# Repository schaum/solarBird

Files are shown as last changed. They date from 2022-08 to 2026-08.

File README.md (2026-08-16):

# Twittering E-Solar-Bird with ATtiny13-Chip

Do you want to improve the world with electronics? Then this solar-powered E-Bird is for you. This bird alternative operates completely autonomously and is friendly in any climate. The bird starts chirping on its own as soon as there's a bit of light.

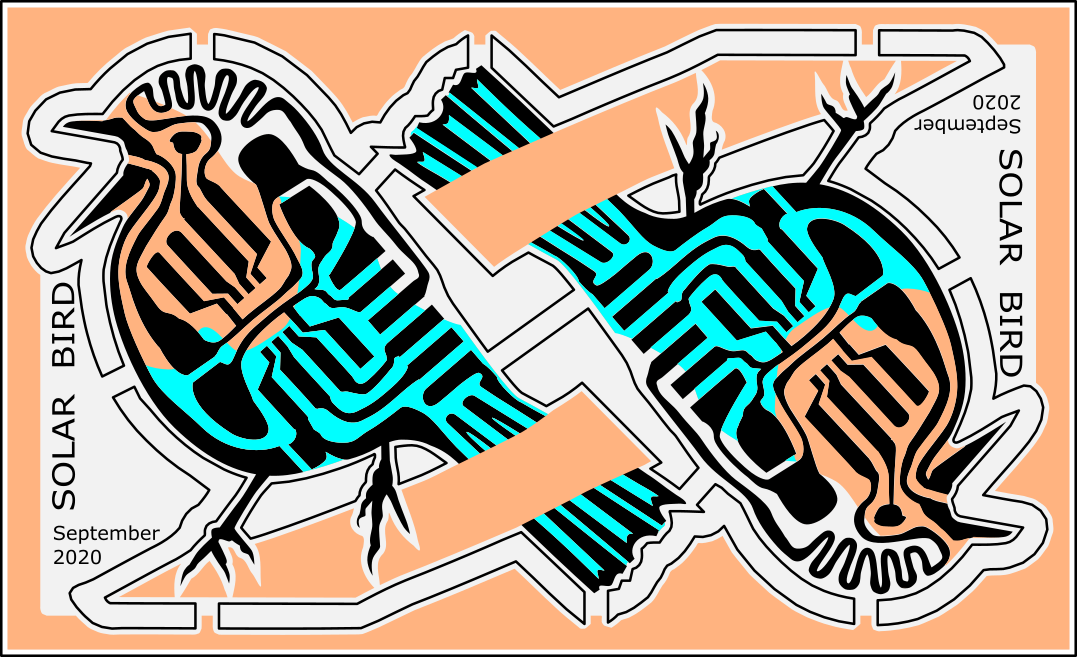
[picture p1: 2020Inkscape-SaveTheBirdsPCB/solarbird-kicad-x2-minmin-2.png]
SolraBird-PCB
This is how the circuit board design looks like. 

Freshly programmed, the bird also twitters. It adjusts its enthusiasm according to light conditions. The program is easily adjustable, which is why we've used this circuit for workshops, for example in schools.

In this project you find my chirping program and circuit board.

Some details for the old, still analog version of the solar bird you can find on [this page](http://mechatronicart.ch/diymakeaway/solarbird).

Protect the species!

This project has grown [within the community](https://mechatronicart.ch/). The basis comes from Christoph Haberer. Sounddesign and circuit board by [taube.xyz](/pick/kontakt), Spring 2011 and September 2020.

For some more pictures, visit [this homepage](https://taube.xyz/pick/solarbird).

## Some hints and advices building

- The twittering program works best on ATtiny13 or ATtiny13V chips. **Avoid the newer ATtiny13A chips.** The reason is, that these newer chips interrupt the programm, when the voltge drops a certain level. This is normally a good thing. But the behavior of the chips without the "A" is more interesting for the solar bird: the internal clock gets slower, and so the chirping gets slower and deeper in sound as well. This is perfect for manipulation of the twittering by making shadows on the solar cell. Also, you can program very fast twitterings and make them hearable when you put the bird into the shadow.
- The circuit board is designed so that you can use SMD-Chips, but as well the DIL-chips with the long legs. Simply bend the legs 90 degrees and solder them onto the surface. No need to drill holes.
- For programming the chip, there are 6 pins in a row on the backbones of the bird, from head to tail: GND, 5V, RESET, SCK, MISO, MOSI. It's easy there to solder a single row of pin-headers.
- If you want to program the chip without disconnecting the piezo speaker, you can add a resistor in between the speaker and the chip. There is a gap on the track in the lower part of the circuit board between pin 5 of the chip and the beak of the bird. Bridge it with a resistor of maybe 1K max.
- If you want to add sensors to the ADC of the chip, beware that the ADC doesn't work securely when the voltage drops very low. The working of the chip with very low voltages is a main feature of this solar bird. Test it well, if it works the way you like!

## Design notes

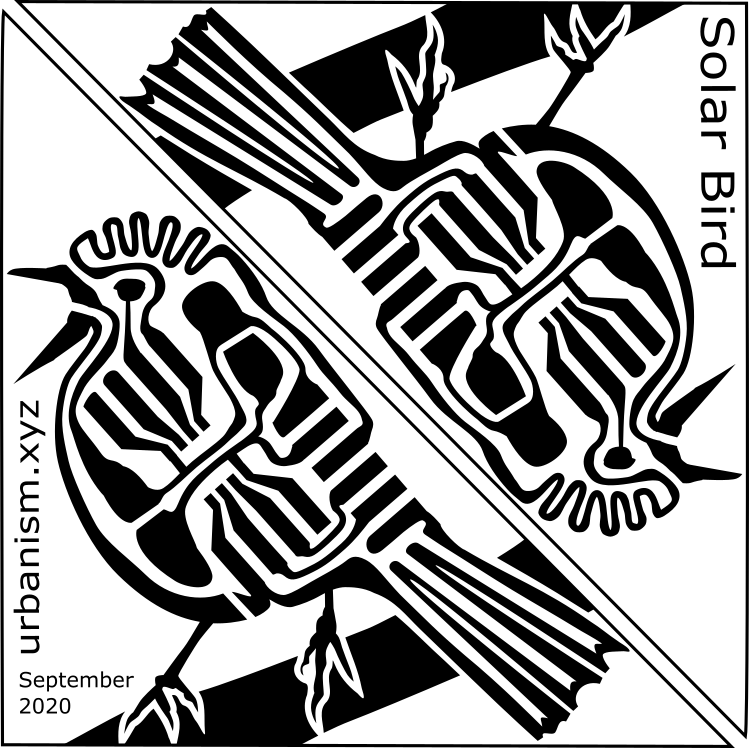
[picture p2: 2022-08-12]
2020Inkscape-SaveTheBirdsPCB/solarbirdx2.png

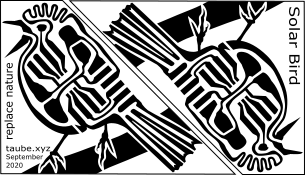
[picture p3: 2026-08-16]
2020Inkscape-SaveTheBirdsPCB/solarbirdx2v2.png

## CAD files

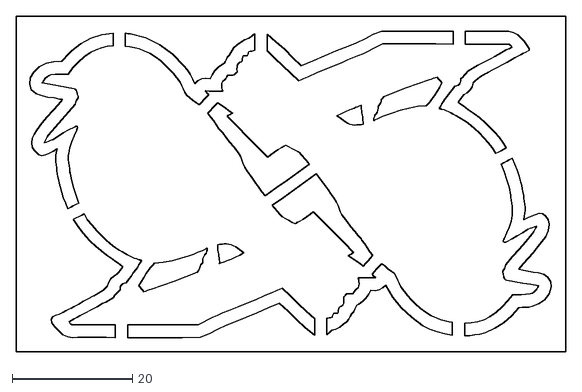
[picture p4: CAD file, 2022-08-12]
2020Inkscape-SaveTheBirdsPCB/solarbird-kicad-x2-minmin-cut.dxf
91.3 x 55.6

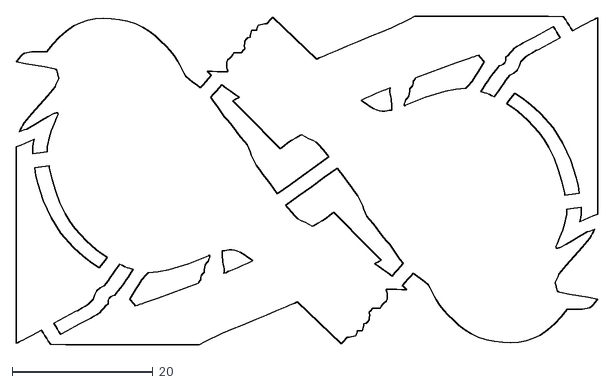
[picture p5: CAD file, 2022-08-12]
2020Inkscape-SaveTheBirdsPCB/solarbird-kicad-x2-cut.dxf
82.6 x 46.7

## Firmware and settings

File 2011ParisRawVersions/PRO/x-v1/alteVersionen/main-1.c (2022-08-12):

 /*************************************************************************

   solar frog

   attiny 13 slow clock low power experiments

   28.9.08 christoph(at)roboterclub-freiburg.de
   15.9.10 urbanbieri(at)gmx.ch

*************************************************************************/
/*************************************************************************

   Hardware
   
   prozessor:   ATtin13
   clock:      128Khz internal oscillator

   PIN1   RESET         
   PIN2   PORTB3/ADC3    ADC- light sensitive sensor  
   PIN3   PORTB4/ADC2      
   PIN4   GND

   PIN5   PORTB0/OC10    piezo controll speaker
   PIN6   PORTB1         record button
   PIN7   PORTB2/ADC1      
   PIN8   VCC

*************************************************************************/
#include <avr/io.h>
#include <avr/eeprom.h>


#define PIEZOSPEAKER 	(1<<PINB0)
#define SENSOR 			(1<<PINB3)
#define BUTTON 			(1<<PINB1)

#define LOADSECONDS 60

#define HZ_1706 2
#define HZ_853 4
#define HZ_586 6
#define HZ_426 8

//GLOBAL VARIABLES
	uint16_t tone_d = 100;
	uint16_t pause_d = 500;
	int8_t pitchstep = 1;

void init_sensor(void){
	
	DDRB &= ~(SENSOR); //set SENSOR pin as input
	// Enable ADC: ADEN to 1.
	// Prescaler 128: ADPS2-0: set to 1
	// enable the Conversion Complete Interrupt: ADIE to 1
	ADCSRA = (1 << ADEN) | (1 << ADPS2) | (1 << ADPS1) | (1 << ADPS0);
}

// sets LED-PWM value from LSR value (light sensitive resistor)
uint8_t start_conversion(void){
// for 8-bit precision I select left Adjustet representation (ADLAR) so that I only have
// to read the ADCH byte. REFS0=0: reference voltage VCC
	ADMUX = (1 << ADLAR) | (0 << REFS0) | 0x11; // 0x01 is PB2, 0x10 is PB4, 0x11 is PB3.
	ADCSRA |= (1 << ADSC);			// Start conversion
	while (!(ADCSRA & (1 << ADIF)));	// wait for conversion complete	
	ADCSRA |= (1 << ADIF);			// clear ADCIF
	return(ADCH);
}

//EEPROM examples from the Attiny13 manual, page 13.
void EEPROM_write(uint8_t ucAddress, uint8_t ucData) { 
	/* Wait for completion of previous write */ 
	while(EECR & (1<<EEPE)); 
	/* Set Programming mode */ 
	EECR = (0<<EEPM1)|(0>>EEPM0);
	/* Set up address and data registers */ 
	EEARL = ucAddress; 
	EEDR = ucData; 
	/* Write logical one to EEMPE */ 
	EECR |= (1<<EEMPE); 
	/* Start eeprom write by setting EEPE */ 
	EECR |= (1<<EEPE); 
}
uint8_t EEPROM_read(uint8_t ucAddress) { 
	/* Wait for completion of previous write */ 
	while(EECR & (1<<EEPE)); 
	/* Set up address register */ 
	EEARL = ucAddress; 
	/* Start eeprom read by writing EERE */ 
	EECR |= (1<<EERE); 
	/* Return data from data register */ 
	return EEDR; 
}

void init_button(){
	DDRB &= ~BUTTON; 	//set pin as input (BUTTON to 0)
	PORTB |= BUTTON;	//turn on pull up resistor
}

void init_timer()
{
   DDRB |= PIEZOSPEAKER; // Piezo as output   
   

   TCCR0A=(1<<COM0A0) | 0x02; //CTC mode and toogle OC0A port on compare match
   TCCR0B=(1<<CS00) ; // no prescaling,
   OCR0A=255; // in CTC Mode the counter counts up to OCR0A
   // CTC-Modefrequency calculation: f=IO_CLC/(2*N*(1+OCR0A)) N:Prescaler
   // e.g. IO_CLK=128KHz, N=1; OCR0A=1 ==> 64Khz
   // e.g. IO_CLK=128KHz, N=1; OCR0A=10 ==> f=6095Hz
   // e.g. IO_CLK=128KHz, N=1; OCR0A=100 ==> f=633Hz
   // e.g. IO_CLK=128KHz, N=1; OCR0A=200 ==> f=318Hz
   // e.g. IO_CLK=128KHz, N=1; OCR0A=255 ==> f=318Hz

   TCCR0B=(1<<CS00) ; // no prescaling,
      
   ///FAST PWM mode and set OC0A ( PB0 ) port on compare match   
   //TCCR0A=(1<<COM0A0) | (1<<COM0A1) | (1<< WGM00 ) | (1<< WGM01 );

   //   TCCR0B=(1<<CS00) | (1<< WGM02 ); // no prescaling, PWM OCR0A update
   //TCCR0B=(1<<CS00) ; // no prescaling,

   //TCCR0B=0x02; // internal clock source devided by 8
    //OCR0A=9; // Compare value

    OCR0A=255; // Counter end   
   // caldulated frequency at 9.6MHz: 1/9.6e6/(8*(124+1))= 9600 Baud
   // bit time = 104,17us
   //TCCR0A=0x02; // CTC-Mode (clear timer on compare match)
}

// duration in 1ms
void delay_ms(uint16_t duration)
{
   uint16_t d;
   uint8_t n;
   uint16_t counter;

   counter=(3*duration);
   // periode duration 586us
   for(d=0;d<counter;d++)
   {
      for(n=0;n<1;n++) PORTB &= ~(PIEZOSPEAKER);
      for(n=0;n<1;n++) PORTB &= ~(PIEZOSPEAKER);
   }
}

#define SPEAKEROFF	TCCR0A=(0x02)
#define SPEAKERON	TCCR0A=((1<<COM0A0) | 0x02)

void invokePattern1(uint16_t duration, uint16_t pause, int8_t pitchstep){
	OCR0A += pitchstep;
	delay_ms(duration);
	OCR0A -= (pitchstep);
	delay_ms(duration);
	OCR0A += pitchstep;
	delay_ms(duration);
	OCR0A += pitchstep;
	delay_ms(duration);
	OCR0A += pitchstep;
	delay_ms(duration);
	OCR0A += pitchstep;
	delay_ms(duration);
	OCR0A -= (3*pitchstep);
	SPEAKEROFF; //PAUSE!
	delay_ms(pause);
	SPEAKERON;
}
void invokePattern2(uint16_t duration, uint16_t pause, int8_t pitchstep){
	delay_ms(duration);
	OCR0A -= pitchstep;
	delay_ms(duration);
	OCR0A -= pitchstep;
	delay_ms(duration);
	OCR0A -= pitchstep;
	SPEAKEROFF; //PAUSE!
	delay_ms(pause<<3);
	SPEAKERON;
}

int main(void)
{  
	uint8_t i; //working variable
	
   // Initiation
   OCR0A = 255;
   init_timer();
   init_sensor();
   init_button();
	
   while(1)
   {
		for(i=0; i<4; i++){
			invokePattern1(tone_d, pause_d, pitchstep);
			if(0b00000100==4)pitchstep++;
			tone_d += 7;
			pause_d -= 1;
		}
		invokePattern2((tone_d<<1), (pause_d<<2), pitchstep);
		
//		SPEAKEROFF;
//		for(i=0 ; i<5; i++) delay_ms(100000);
//		SPEAKERON;
		
		if(OCR0A<=16)OCR0A=255;
		if(pitchstep<2)pitchstep=31;
		if(tone_d>600)tone_d=40;
		if(pause_d<10)pause_d=40;
		if(pitchstep<8 && OCR0A<40){
			tone_d=1;
			pitchstep = 31;
		}
   }
   return 0;
}
/***************************************************************************
*   
*   (c) 2008 christoph(at)roboterclub-freiburg.de
*       2010 urbanbieri(at)gmx.ch
***************************************************************************
*   This program is free software; you can redistribute it and/or modify  *
*   it under the terms of the GNU General Public License as published by  *
*   the Free Software Foundation version 2 of the License,                *
*   If you extend the program please maintain the list of authors.        *
*   If you want to use this software for commercial purposes and you      *
*   don't want to make it open source, please contact the authors for     *
*   licensing.                                                            *
***************************************************************************/ 

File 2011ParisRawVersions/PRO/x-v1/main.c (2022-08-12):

 /*************************************************************************

   solar bird

   attiny13 power experiments

   28.9.08 christoph(at)roboterclub-freiburg.de
   15.5.11 urban.bieri(at)gmx.ch

*************************************************************************/
/*************************************************************************

   Hardware
   
   prozessor:   ATtin13
   clock:      9.6 Mhz internal oscillator

   PIN5, PORTB0/OC10: piezo controll speaker

*************************************************************************/
#include <avr/io.h>

#define PIEZOSPEAKER 	(1<<PINB0)

#define SPEAKEROFF	TCCR0A=(0x02) // PIN to normal port operation
#define SPEAKERON	TCCR0A=((1<<COM0A0) | 0x02) // toggle PIN

//GLOBAL VARIABLES
	uint16_t tone_d = 101;
	uint16_t pause_d = 500;
	int8_t pitchstep = 1;

void init_timer(){
   DDRB |= PIEZOSPEAKER; // Piezo as output   

   TCCR0A=(1<<COM0A0) | 0x02; //CTC mode and toogle OC0A port on compare match
   TCCR0B=(1<<CS00) ; // no prescaling,
   OCR0A=255; // in CTC Mode the counter counts up to OCR0A     
}

// unspecified delay time
void delay_(uint16_t duration){
   uint16_t d;
   uint8_t n;
   uint16_t counter;

   counter=(3*duration);
   // periode duration ??
   for(d=0;d<counter;d++){
      for(n=0;n<1;n++) PORTB &= ~(PIEZOSPEAKER);
      for(n=0;n<1;n++) PORTB &= ~(PIEZOSPEAKER);
   }
}

void invokePattern1(uint16_t duration, uint16_t pause, int8_t pitchstep){
	OCR0A = OCR0A - pitchstep;
	delay_(duration);
	OCR0A -= pitchstep;
	delay_(duration);
	OCR0A -= pitchstep;
	delay_(duration);
	OCR0A += (2*pitchstep);
	SPEAKEROFF; //PAUSE!
	delay_(pause);
	SPEAKERON;
}
void invokePattern2(uint16_t duration, uint16_t pause, int8_t pitchstep){
	delay_(duration<<1);
	OCR0A -= pitchstep+4;
	SPEAKEROFF; //PAUSE!
	delay_(pause<<2);
	SPEAKERON;
}
void invokePattern1b(uint16_t duration, uint16_t pause, int8_t pitchstep){
	OCR0A += pitchstep;
	delay_(duration);
	OCR0A -= (pitchstep);
	delay_(duration);
	OCR0A += pitchstep;
	delay_(duration);
	OCR0A += pitchstep;
	delay_(duration);
	OCR0A += pitchstep;
	delay_(duration);
	OCR0A += pitchstep;
	delay_(duration);
	OCR0A -= (3*pitchstep);
	SPEAKEROFF; //PAUSE!
	delay_(pause);
	SPEAKERON;
}
void invokePattern2b(uint16_t duration, uint16_t pause, int8_t pitchstep){
	delay_(duration);
	OCR0A -= pitchstep;
	delay_(duration);
	OCR0A -= pitchstep;
	delay_(duration);
	OCR0A -= pitchstep;
	SPEAKEROFF; //PAUSE!
	delay_(pause<<3);
	SPEAKERON;
}

int main(void)
{  
	// working variable
	uint8_t i;
	
	// Initiation
	init_timer();
	
	while(1)
	{
		for (i = 0; i < 5; ++i)
		{
		for(i=0; i<4; i++){
			invokePattern1(tone_d, pause_d, pitchstep);
			pitchstep++;
			tone_d += 20;
			pause_d -= 5;
		}
		invokePattern2((tone_d<<1), (pause_d<<2), pitchstep);
		
		if(OCR0A<=16)OCR0A=255;
		if(pitchstep>32)pitchstep=1;
		if(tone_d>200)tone_d=20;
		if(pause_d<20)pause_d=200;
		if(pitchstep<8 && OCR0A<40){
			tone_d=1;
			pitchstep = 0;
		}
		}

		SPEAKEROFF;
		for(i=0 ; i<5; i++) delay_(10000);
		SPEAKERON;
		
		for (i = 0; i < 10; ++i)
		{
		for(i=0; i<4; i++){
			invokePattern1b(tone_d, pause_d, pitchstep);
			if(0b00000100==4)pitchstep++;
			tone_d += 7;
			pause_d -= 1;
		}
		invokePattern2b((tone_d<<1), (pause_d<<2), pitchstep);
		
//		SPEAKEROFF;
//		for(i=0 ; i<5; i++) delay_(100000);
//		SPEAKERON;
		
		if(OCR0A<=16)OCR0A=255;
		if(pitchstep<2)pitchstep=31;
		if(tone_d>600)tone_d=40;
		if(pause_d<10)pause_d=40;
		if(pitchstep<8 && OCR0A<40){
			tone_d=1;
			pitchstep = 31;
		}
		}
	}
	return 0;
}
/***************************************************************************
*   
*   (c) 2008 christoph(at)roboterclub-freiburg.de
*		2011 urbanbieri(at)gmx.ch
*
***************************************************************************
*   This program is free software; you can redistribute it and/or modify  *
*   it under the terms of the GNU General Public License as published by  *
*   the Free Software Foundation version 2 of the License,                *
*   If you extend the program please maintain the list of authors.        *
*   If you want to use this software for commercial purposes and you      *
*   don't want to make it open source, please contact the authors for     *
*   licensing.                                                            *
***************************************************************************/ 

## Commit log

2017-01-10 add PCBs
2022-08-12 Add new SGMK SMD-DIL-8 Style PCB. Protect the birds!
    [solarbird-kicad-x2-cut.dxf, solarbird-kicad-x2-minmin-cut.dxf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]
